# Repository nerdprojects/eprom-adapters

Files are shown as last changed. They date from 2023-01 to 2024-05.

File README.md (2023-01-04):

# EPROM Adapters

## SST39SF040 to M27C4001

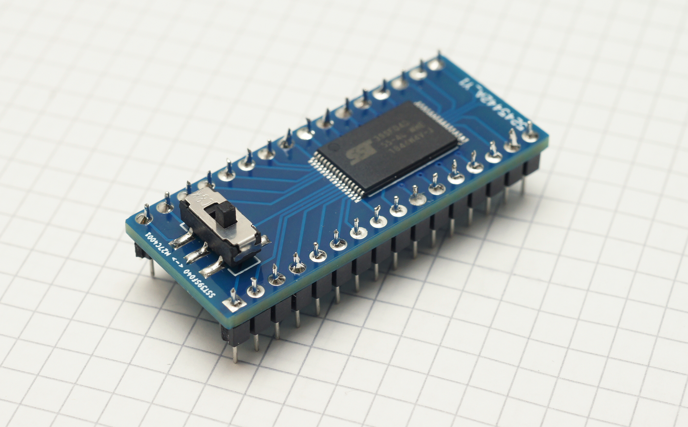
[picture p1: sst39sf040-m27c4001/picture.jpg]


This is an adapter PCB that can be used to make the "Microchip SST39SF040" pin-compatible with the M27C4001 EPROM.

An alternative to this adapter could be the "Winbond W27E040" chip, which is pin-compatible with the M27C4001.

I used it for patching ROMs in my pinball machines:
https://github.com/nerdprojects/pinball-cvsd-patcher

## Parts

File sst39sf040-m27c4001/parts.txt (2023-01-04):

DPDT Switch SMD:
JS202011SCQN

Flash-Memory:
SST39SF040-55-4C-WHE

Pin-Headers:
350-80-164-00-006101

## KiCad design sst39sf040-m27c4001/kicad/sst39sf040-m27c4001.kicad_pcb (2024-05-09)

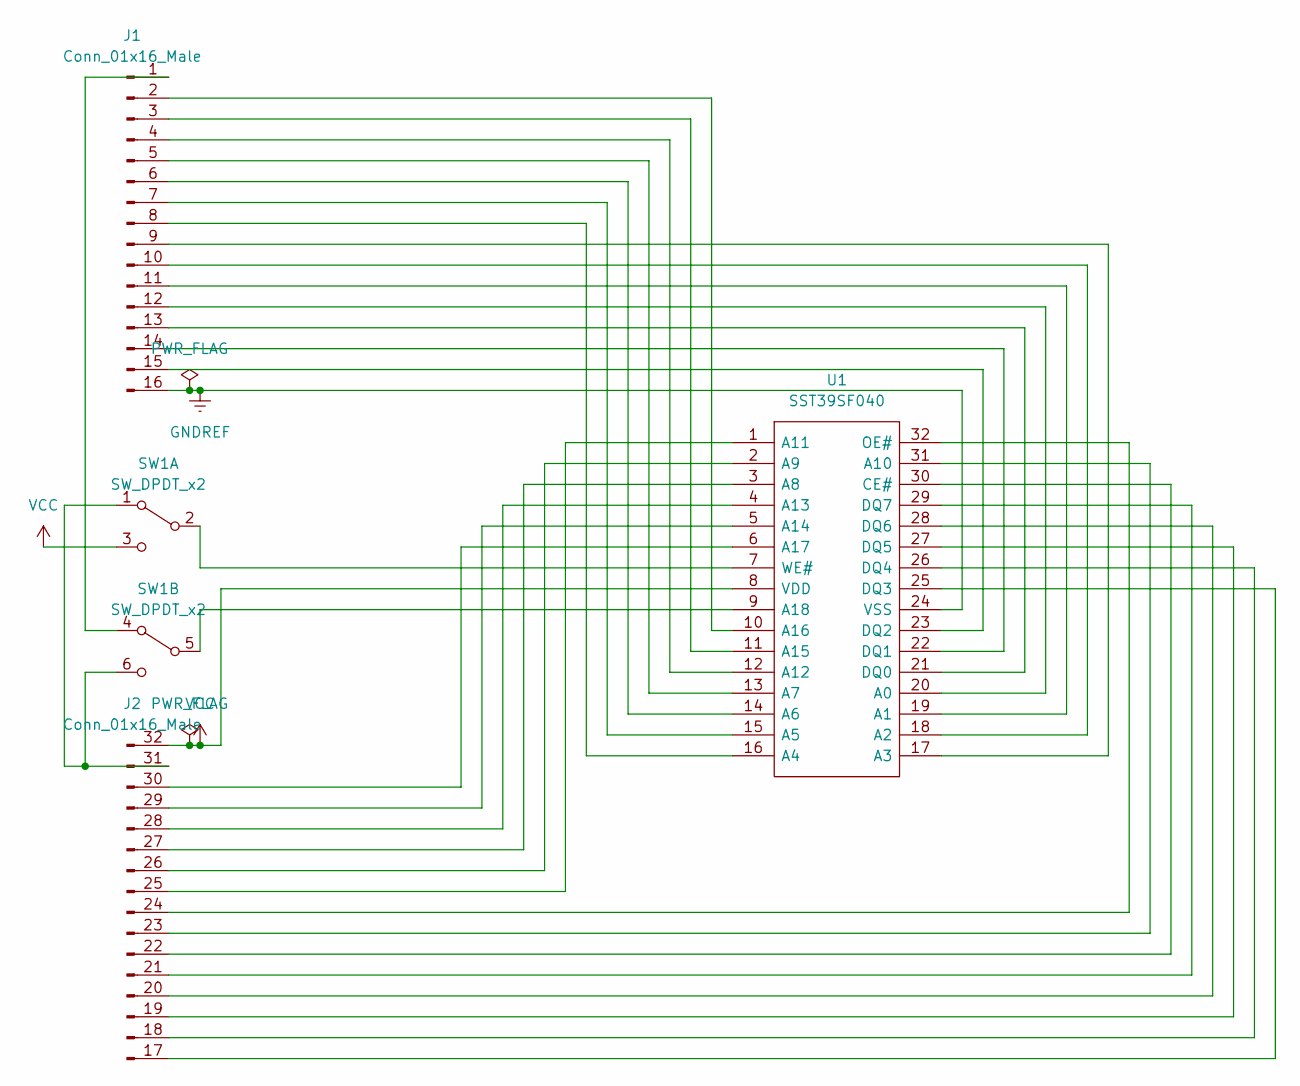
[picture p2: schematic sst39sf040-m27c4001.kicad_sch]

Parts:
J1, J2: Conn_01x16_Male; PinHeader_1x16_P2.54mm_Vertical
SW1: SW_DPDT_x2; JS202011SCQN
U1: SST39SF040; SOP50P1400X120-32N; Manufacturer_Part_Number SST39SF040-45-4I-WHE-T

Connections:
GNDREF: J1.16, U1.24 (VSS)
unnamed: J1.1, SW1.4 (A)
unnamed: J1.2, U1.10 (A16)
unnamed: J1.3, U1.11 (A15)
unnamed: J1.4, U1.12 (A12)
unnamed: J1.5, U1.13 (A7)
unnamed: J1.6, U1.14 (A6)
unnamed: J1.7, U1.15 (A5)
unnamed: J1.8, U1.16 (A4)
unnamed: J1.9, U1.17 (A3)
unnamed: J1.10, U1.18 (A2)
unnamed: J1.11, U1.19 (A1)
unnamed: J1.12, U1.20 (A0)
unnamed: J1.13, U1.21 (DQ0)
unnamed: J1.14, U1.22 (DQ1)
unnamed: J1.15, U1.23 (DQ2)
unnamed: J2.17, U1.25 (DQ3)
unnamed: J2.18, U1.26 (DQ4)
unnamed: J2.19, U1.27 (DQ5)
unnamed: J2.20, U1.28 (DQ6)
unnamed: J2.21, U1.29 (DQ7)
unnamed: J2.22, U1.30 (CE#)
unnamed: J2.23, U1.31 (A10)
unnamed: J2.24, U1.32 (OE#)
unnamed: J2.31, SW1.1 (A), SW1.6 (C)
unnamed: J2.25, U1.1 (A11)
unnamed: J2.26, U1.2 (A9)
unnamed: J2.27, U1.3 (A8)
unnamed: J2.28, U1.4 (A13)
unnamed: J2.29, U1.5 (A14)
unnamed: J2.30, U1.6 (A17)
unnamed: SW1.2 (B), U1.7 (WE#)
unnamed: SW1.5 (B), U1.9 (A18)
VCC: J2.32, SW1.3 (C), U1.8 (VDD)

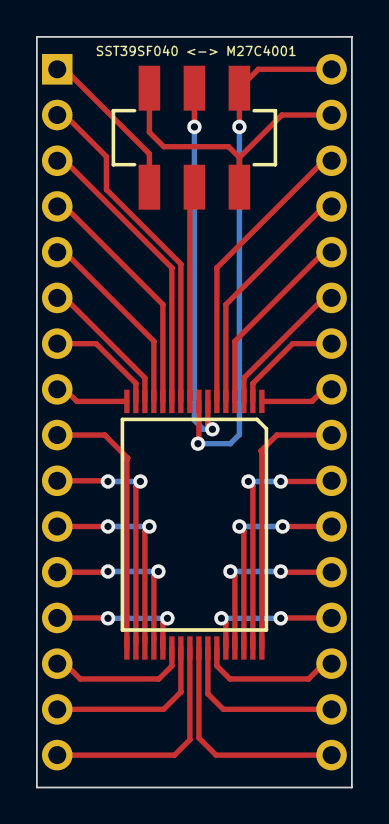
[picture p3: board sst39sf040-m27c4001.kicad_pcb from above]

Board: 2 copper layers, 17.5 x 41.7 mm, 4 parts (0 on the bottom side), 34 nets.
